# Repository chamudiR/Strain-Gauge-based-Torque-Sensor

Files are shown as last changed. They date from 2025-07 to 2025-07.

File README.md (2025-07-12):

# Strain Gauge-Based Torque Sensor  
*University of Moratuwa – EN2160 Electronic Design Realization*

---

## Overview  
This project is a strain gauge-based torque sensor designed for accurate, robust, and wireless torque measurement in industrial settings. It employs dual-grid shear strain gauges in a full Wheatstone bridge configuration, advanced signal conditioning, wireless power and data transmission, and a compact shaft-mounted PCB.

---

## Features
- **Measurement Range:** Up to 50 N·cm  
- **Wireless Power & Data:** Inductive power transfer and Bluetooth Low Energy (BLE) transmission  
- **High Sensitivity:** Full-bridge Wheatstone configuration with dual-grid strain gauges  
- **Robust Construction:** Stainless steel enclosure, precision shaft, and flex PCB  
- **Real-Time Monitoring:** BLE-enabled, compatible with mobile and desktop visualization tools  

---

## Hardware Architecture

| Subsystem | Key Components | Description |
|---|---|---|
| **Sensing** | SGT-2DC/350-SY11 Dual-Grid Strain Gauges | Measures torsional strain on shaft at ±45° |
| **Signal Conditioning** | INA333 Instrumentation Amplifier, OPA336 Offset Circuit | Amplifies and zeroes bridge output for ADC |
| **Data Acquisition**| HX711 24-bit ADC | High-resolution digitization of analog signal |
| **Processing & BLE**| DA14531 BLE MCU | Reads ADC, processes data, transmits via Bluetooth |
| **Power** | Inductive Tx/Rx coils, Boost Converter | Wireless power delivery to rotating shaft electronics |
| **Enclosure** | Stainless Steel, Bearings, Flex PCB | Protects internals, enables rotation, houses electronics |

---

## Getting Started

### 1. Hardware Assembly  
- Mount dual-grid strain gauges at ±45° on the shaft’s central region, 180° apart.  
- Assemble the two-part stainless steel enclosure with bearings securing the shaft ends.  
- Attach the flex PCB and receiver coil to the shaft; mount the transmitter coil concentrically inside the enclosure.

### 2. Powering the System  
- Connect a 5V DC supply to the transmitter PCB via USB.  
- The transmitter coil wirelessly powers the shaft electronics via inductive coupling.

### 3. Firmware & Programming  
- Program the DA14531 BLE MCU using Keil MDK and SmartBond Flash Programmer.  
- MCU reads HX711 ADC data and streams torque values over BLE.  
- Device advertises as BLE peripheral for real-time data transmission.

### 4. Data Visualization  
- Use a BLE-enabled app or custom software to receive and display real-time torque data.  
- Data format: 24-bit signed values scaled through calibration.

---

## Calibration & Testing

- **Zero Calibration:** Use the OPA336 offset circuit to zero output with no torque applied.  
- **Span Calibration:** Apply known torques and record output to create calibration curves.  
- **Validation:** Verify accuracy by comparing with reference torque instruments.

---

## Bill of Materials (Key Items)

| Category | Item/Model | Qty | Notes |
|---|---|-----|---|
| Strain Gauge | SGT-2DC/350-SY11 | 1 | Omega Engineering |
| Instrumentation Amp | INA333, OPA336 | 2 | Signal conditioning |
| ADC | HX711 | 1 | 24-bit, digital |
| MCU | DA14531 | 1 | BLE, ultra-compact |
| Power | Inductive Tx/Rx coils | 2 | Wireless power |
| Enclosure | Stainless steel, bearings | 1 | Robust protection |
| PCB | Flex PCB | 1 | Shaft-mounted |

---

## Schematic & PCB Design  
- Detailed schematics cover transmitter, receiver, booster, instrumentation amplifier, offset circuit, ADC, and MCU.  
- Two-layer polyimide flex PCB designed with a component-free center area for shaft mounting and teardrop pads for mechanical strength.

---

## Software Structure

- **BLE Service:** Custom GATT profile for torque data streaming.  
- **GPIO Setup:** Dedicated pins for HX711, status LED, SPI flash.  
- **HX711 Integration:** Timer-based data acquisition with endian conversion and BLE notifications.

---

## Maintenance & Troubleshooting

- **Enclosure Access:** Loosen bolts to open and service internal components.  
- **PCB/Flex Issues:** Inspect for cracks or delamination, especially near bends.  
- **Wireless Power:** Ensure proper coil alignment for optimal power transfer.  
- **Signal Noise:** Use shielded cables and proper grounding to minimize interference.

---

## References  
- Component datasheets: OPA336, INA333, HX711, DA14531  
- Manufacturer application notes: Omega Engineering, Flintec  
- Project design report for detailed theory, calculations, and simulations  

---

## Authors  
Aashir M.R.M., Basith M.N.A., Kumarage R.V., Manawadu D.N., Manawadu M.D., Munavvar M.A.A., Ransika L.G.C., Samuditha H.K.P.

---

## License  
This project is for academic and research purposes at the University of Moratuwa. For reuse or adaptation, please contact the project authors or supervising faculty.

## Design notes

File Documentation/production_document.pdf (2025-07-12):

## University of Moratuwa

## Faculty of Engineering

## Department of Electronic and Telecommunication Engineering


## EN2160 - Electronic Design Realization

## Production Document- Strain Gauge based Torque Sensor

Aashir M.R.M. | 220004M
Basith M.N.A. | 220071M
Kumarage R.V. | 220343B
Manawadu D.N. | 220380J
Manawadu M.D. | 220381M
Munavvar M.A.A. | 220405T
Ransika L.G.C. | 220514C
Samuditha H.K.P. | 220562U

May 22, 2025

## Contents

1 Production Documentation | 3
2 Mechanical Engineering Instructions | 4
3 Manufacturing Summary | 8
4 PCB Assembly Instructions | 8
5 | Wiring and Connections | 11
6 Programming Instructions | 12
7 Testing Procedure | 13
8 Packaging and Shipping | 14

May 22, 2025

## 1 Production Documentation

This section provides the full set of instructions and technical information necessary to reproduce, assemble, wire, program, and test the strain gauge-based torque sensor. It is intended for use by engineers and technicians during manufacturing, maintenance, and future development.

### 1.1 System Architecture Overview

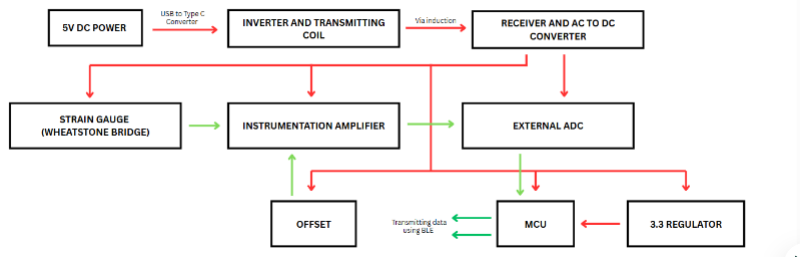
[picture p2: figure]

Figure 1: High-level system block diagram of the torque sensor

### 1.2 Complete Bill of Materials (BoM)

Category | Component Name | Description / Notes
Sensors | SGT-2DC/350-SY11 | Dual-grid strain gauges (Omega, 350 Ω)
Amplifiers | AD8293G160 OPA336 | Instrumentation amplifier (Fixed gain 160) Secondary precision op-amp
ADC | HX711 | 24-bit ADC for bridge signals (external to MCU)
DAC | MCP4728 | 12-bit DAC for offset adjustment
Microcontroller | DA14531 TINY Module | BLE 5.1 microcontroller
Power Supply | Qi Wireless TX/RX Coil Pair Rectifier and Regulator Cir-cuit USB-C Connector | Wireless power coils (inductive) 5 V output from Rx coil 5 V input source
Passives | Resistors (Precision, 1%) Capacitors (Ceramic, MLCC) | Signal conditioning Decoupling, filtering
Connectors | Terminal Block 3-pin JST/SMD Headers | Strain gauge terminal access Module interfacing
PCB | Custom PCB | Main control and signal board
Mechanical | Shaft (AISI 1018 Steel) Bearings Molded Enclosure Mounting Bolts and Screws | 17 mm diameter, torque sensing region Radial bearings for shaft rotation Two-part, bolt-closed enclosure M3/M4 as per enclosure design
Miscellaneous | Ribbon Cables Epoxy Adhesive Shielded Twisted Pair Cable | For flexible wiring on shaft For strain gauge bonding For signal integrity

Table 1: Complete Bill of Materials for Torque Sensor System (Simplified)

## 2 Mechanical Engineering Instructions

This section outlines the detailed mechanical steps involved in fabricating the torque sensor’s physical components, assembling the mechanical system, and preparing the shaft for strain gauge bonding and environmental protection. It is intended for technicians and engineers responsible for the physical realization of the sensor.

### 2.1 Shaft Fabrication

1. Material Selection: Use Aluminum Alloy 6061-T6 for its excellent machinability, corrosion resistance, and favorable strength-to-weight ratio. Yield strength: 275 MPa. Elastic modulus: 69 GPa. This alloy is well-suited for lightweight torque sensor applications where moderate stress levels are expected.

2. Dimensions: Turn the shaft on a lathe to a final diameter of 17 mm and ensure a central narrow region where strain gauges will be mounted. Maintain a shaft length that accommodates bearing insertion and torque transmission interfaces at both ends.
3. Surface Finish: Achieve a surface roughness of Ra less than 0.4 µm using progressively finer polishing techniques. A smooth surface is essential for effective strain gauge bonding and reducing localized stress concentrations.
4. Concentricity and Balancing: Verify shaft symmetry and ensure dynamic balance to avoid rotational vibration during testing and real-time use.

### 2.2 Enclosure Design and Assembly

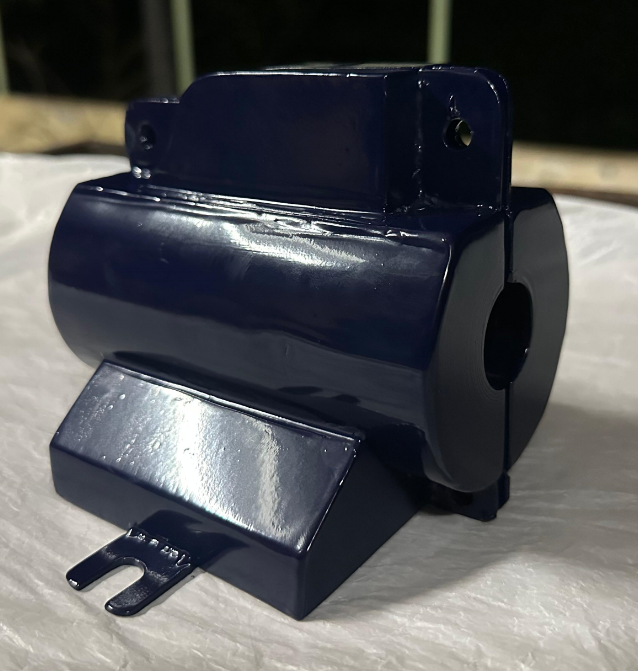
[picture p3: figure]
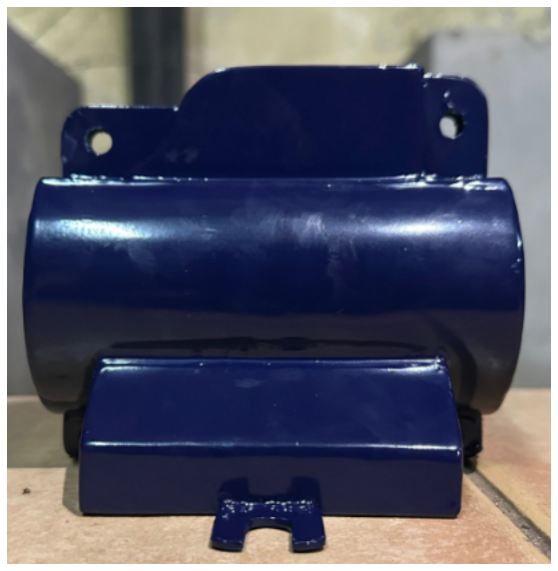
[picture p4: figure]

Figure 2: Final torque sensor enclosure fabricated from stainless steel

1. Enclosure Type: The finalized enclosure is fabricated from corrosion-resistant stainless steel, selected for its superior structural integrity, environmental resilience, and suitability for industrial use. It is constructed from two main welded halves that follow the original CAD model dimensions and tolerances.
2. Construction Method: The two halves are joined using a bolted interface with flange extensions. Welded seams ensure mechanical rigidity while maintaining precision. Alignment notches and pilot holes are incorporated during fabrication to aid accurate mating and prevent misalignment during assembly.
3. Internal Features: The interior of the housing includes:
- Precision-machined bearing grooves on both sides to ensure accurate shaft alignment and reduce radial play.
- Welded metal brackets for mounting the internal PCB assemblies securely in a vibrationisolated configuration.
- A fixed holder for the wireless power receiver coil aligned with the external transmitter.
4. Modularity and Serviceability: The design supports easy disassembly using standard hex bolts. The modular structure allows for straightforward access during recalibration, firmware reprogramming, or component replacement.

5. Environmental Protection: To withstand demanding industrial environments:
- The outer surface is treated with anti-corrosion finishing (e.g., brushed stainless or powder coating).
- Internal cavities are sealed with high-grade silicone gaskets to prevent ingress of dust and moisture.
6. Cable Routing and Interface: Cable access holes are machined at the rear end and fitted with metallic cable glands for strain relief and environmental sealing. These are positioned to allow routing of power, debug, and signal wires without affecting the shaft’s rotational clearance.
7. Mechanical Stability: The shaft is supported within the enclosure using deep-groove ball bearings mounted in the machined recesses. The enclosure’s mass and rigidity reduce vibrational coupling and ensure minimal distortion in the strain measurements.

### 2.3 Strain Gauge Installation Procedure

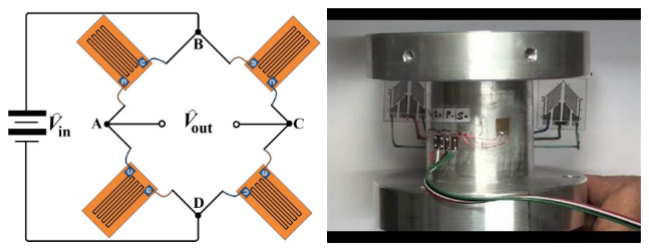
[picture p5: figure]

Figure 3: Strain gauge placement

### 3.1 Optimal Placement Identification

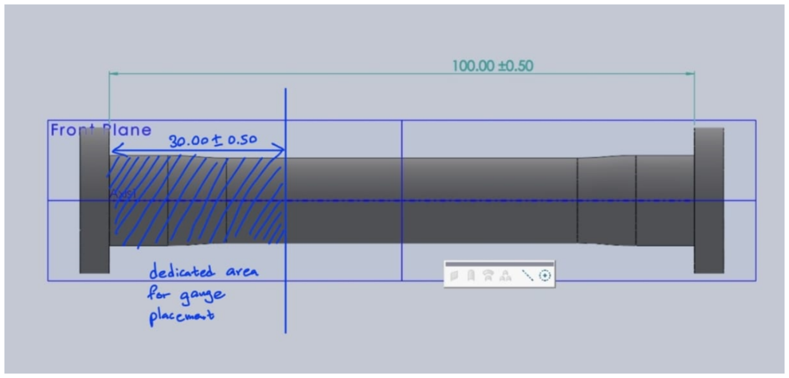
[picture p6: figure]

Figure 4: Strain gauge placement

1. Finite Element Analysis (FEA): Use FEA tools (e.g., SolidWorks Simulation) to simulate shear stress under applied torque. Fix one end of the shaft and apply a known torque at the other.

2. Distortion Mapping: Locate the region of maximum shear strain
3. Marking Gauge Position: Using a micrometer and a wrap-around marking template, draw layout lines at ±45° from the shaft axis, 180° apart.

### 3.2 Shaft Surface Preparation

1. Degrease: Wipe with isopropyl alcohol or acetone using a lint-free cloth.
2. Abrasive Polishing: Polish with 600–1200 grit emery paper in a single axial direction to slightly roughen the bonding area.
3. Mark and Align: Re-mark layout lines post-abrasion with fine pencil or scribing tool.
4. Final Cleaning: Rinse again with alcohol and allow to air dry in a dust-free environment.

### 3.3 Bonding the Strain Gauges

1. Adhesive: Use SBond conductive adhesive suitable for shear/torque sensors.
2. Gauge Handling: Using tweezers, gently position the dual-grid strain gauges on the prepared shaft.
3. Bonding Method: Apply a small quantity of SBond to the marked area. Place the gauge and press uniformly using a silicone pad and apply a 0.5–1 kg/cm² load via clamp or weight.
4. Pressure Hold: Maintain pressure for 20 minutes to allow partial cure and initial fixation.
5. Curing: Place the shaft in an oven and cure at 180 °C for 2 hours to fully activate the SBond polymer. Ensure no mechanical load is applied during this step.

### 2.4 Wiring of Strain Gauges

1. Soldering: Solder cables to the strain gauge pads using a fine-tipped soldering iron (max 250 °C).
2. Strain Relief: Fix wires to the shaft using small dabs of epoxy or mechanical clamps 10–20 mm from solder joints.
3. Cable Routing: Guide wires through a terminal block or solder pad mounted near the shaft edge. Match wire lengths to maintain bridge symmetry.
4. Shielding: Use twisted-pair shielded wires where signal wires leave the shaft enclosure.

### 2.5 Protective Coating Application

1. Coating Type: Use polyurethane or silicone-based conformal coating (e.g., MG Chemicals 422B).
2. Application Method: Apply thin, even layers using a small brush or airbrush, ensuring full coverage of strain gauge and solder joints.
3. Cure Time: Allow the coating to cure at room temperature for 12–24 hours. Do not operate the sensor during this period.
4. Verification: Inspect under magnification to confirm complete encapsulation.

### 2.6 Final Mechanical Integration

1. Insert Bearings: Press bearings into the enclosure ends with proper alignment.
2. Mount Shaft: Insert shaft through bearings, ensuring smooth rotation with minimal play.
3. Align Wireless Coils: Align the wireless power transmitter coil in the enclosure with the receiver coil on the shaft. Test for maximum inductive coupling distance.
4. Seal the Enclosure: Fasten enclosure bolts if needed. Check torque ratings to avoid deformation.
5. Label Components: Apply component labels and serial numbers externally for traceability.

Note: All assembly steps should be performed in an ESD-safe, humidity-controlled lab environment to ensure long-term sensor reliability.

## 3 Manufacturing Summary

The final torque sensor assembly required a multidisciplinary manufacturing process involving mechanical fabrication, PCB assembly, strain gauge bonding, and precision calibration. Below is a summary of the key manufacturing steps:

- Shaft Machining: CNC-turned from Aluminum 6061 with a final diameter of 17 mm. Middle region polished for strain gauge bonding.
- Strain Gauge Installation: Dual-grid shear strain gauges bonded at ±45° using SBond adhesive; heat-cured at 180°C for 2 hours.
- Enclosure Fabrication: TIG-welded stainless steel housing with precision bearing slots, coil recess, and PCB mounting brackets.
- PCB Assembly: Surface-mounted components on 2-layer flexible polyimide PCB. Layout optimized for shaft conformity and noise immunity.
- Wireless Coil Integration: Receiver coil mounted on shaft; aligned precisely with transmitter using fixture-guided assembly.
- System Calibration: Torque applied via known weights. Voltage readings mapped, offset/gain applied to firmware.

## 4 PCB Assembly Instructions

### 4.1 PCB Assembly Instructions

The following instructions outline the complete process for assembling the printed circuit board (PCB) used in the torque sensor system. Proper PCB assembly ensures optimal electrical performance, signal integrity, and mechanical reliability.

### 1. Preparation and Inspection

(a) Visual Inspection of Bare PCB: Inspect the PCB for fabrication defects, such as incomplete vias, scratches, or delamination. Verify silkscreen alignment and layer registration.

(b) Clean the PCB Surface: Use isopropyl alcohol and lint-free wipes to remove oxidation or flux residues before beginning component placement.
(c) Gather Required Tools and Materials:
- ESD mat and wrist strap
- Fine-tip soldering iron (350°C)
- Solder wire (0.5mm, Sn63Pb37 or SAC305)
- Solder paste and hot air rework station (if reflow soldering is used)
- Tweezers, flux pen, magnifying glass/microscope
- Multimeter for continuity testing

### 2. Component Placement Order

Follow the standard order of assembly to ensure accessibility and minimize errors:

(a) Passive SMD Components: Begin with 0402/0603 resistors, capacitors, and ferrite beads. Use tweezers and place on pre-applied solder paste or fluxed pads.
(b) ICs and Amplifiers: Place precision analog components such as the AD8293G160, OPA336, and MCP4728 with correct pin orientation. Avoid overheating sensitive analog ICs.
(c) Microcontroller and ADC: Mount the DA14531 and HX711 modules. Ensure proper alignment of WLCSP pads or castellated edges.
(d) Connectors and Headers: Insert JST, terminal blocks, USB-C connectors, or test headers.
(e) Inductive Power Components: Solder coils, MOSFET drivers, and rectification circuits for wireless power reception. Maintain spacing from analog circuitry.

### 3. Soldering Process

(a) Manual Soldering (if applicable): Apply solder to each pad with a fine tip iron. For ICs, use drag soldering with flux to ensure even pin contact.
(b) Hot Air Reflow (optional): Preheat the board and reflow at 220–240°C peak. Follow manufacturer reflow profiles for temperature-sensitive components.
(c) Check for Bridges and Cold Joints: Use magnification to inspect solder joints. Rework any poor joints with flux and fresh solder.
(d) Clean Flux Residue: Remove excess flux with isopropyl alcohol and a soft brush to prevent corrosion and leakage currents.

### 4. Assembly Best Practices

- Place decoupling capacitors as close as possible to IC power pins.
- Avoid placing high-speed digital lines close to analog signal paths.
- Ensure clearance between high-voltage coil components and signal circuitry.

### 5. Post-Assembly Inspection and Testing

(a) Continuity Check: Verify all power rails and signal lines are properly connected and there are no shorts between adjacent pins.
(b) Power-Up Test: Connect 5V via USB and check power LED, voltage regulators, and check for overheating components.
(c) Programming Interface Test: Flash a simple test program to the DA14531 and verify BLE broadcast or UART output.
(d) Signal Path Test: Apply a known input to the strain gauge terminals and confirm valid output at the amplifier stage using an oscilloscope.

### 4.2 Flex PCB Implementation for Shaft-Mounted Sensor

The torque sensor PCB was designed as a two-layer flexible printed circuit (flex PCB) to meet the mechanical and operational requirements of being mounted directly on a rotating shaft. This section provides production-oriented details necessary for fabrication, inspection, and reliable assembly.

### 1. Purpose of Flex PCB

The flex PCB enables direct integration with the shaft, offering a lightweight and vibrationtolerant solution that eliminates the need for separate cabling or rotating slip rings. It provides the following key production benefits:

- Rotational Mounting Capability: Conforms directly to a 17 mm shaft without interfering with shaft rotation.
- Reduced Wiring Complexity: Minimizes moving wires and connectors, reducing points of failure.
- Vibration Tolerance: Maintains reliable operation in high-vibration environments due to flexible substrate and secure solder joints.

### 2. Key Production Notes

- Central Bend Region: Keep free of components and vias to allow smooth wrapping around shaft. Ensure 10 mm margin from each side of the shaft bend zone.
- Copper Patterning: Use horizontal hatched fill for ground plane instead of solid fill to maintain flexibility and prevent copper cracking.
- Trace Layout: Route critical signals perpendicular to bend direction. Use rounded corners and curved traces for mechanical longevity.
- Teardrops: All pad-to-trace junctions must use teardrop geometries to prevent delamination.
- Surface Mount Devices: Place all SMD components on the top layer. No throughhole components should be used.

### 3. Assembly Guidelines

- Fixturing During Soldering: Use a stainless steel flat fixture to hold the flex board during reflow soldering to avoid warping.

- Underfill (Optional): For high-vibration applications, epoxy underfill may be applied under key ICs (e.g., DA14531, HX711) after soldering.
- Strain Relief: Cables leaving the flex board (e.g., to strain gauges or power coil) should be anchored using polyimide tape or hot glue to prevent peel force on pads.
- Inspection: Use magnification to inspect for cracked pads, lifted copper, and delamination around bend regions.

### 4. Test Point Integration

Dedicated test points were added for:

- HX711 CLK and DOUT
- BLE module power and UART
- Amplifier output and DAC reference

This allows signal probing during manufacturing and later servicing.

### 5. Conclusion for Production Use

The flex PCB design used in this torque sensor enables compact, durable, and precise sensing on a moving platform. The production and handling requirements outlined above must be strictly followed to ensure mechanical stability and electrical integrity over long-term operation.

## 5 Wiring and Connections

Proper wiring is essential to maintain signal integrity, minimize electromagnetic interference (EMI), and ensure reliable, long-term operation of the torque sensor system. This section outlines both the wiring best practices and the circuit integration flow necessary for accurate signal handling and power distribution.

### 5.1 Wiring Guidelines

- Shielded Twisted Pair Wiring: Use shielded twisted pair (STP) cables for all analog signal lines between strain gauges and the instrumentation amplifier (AD8293G160). This minimizes susceptibility to ambient EMI.
- Symmetric Routing: Maintain equal-length signal paths from the strain gauges to the amplifier inputs to preserve bridge balance. Use color-coded or tagged wires to clearly identify each node.
- Strain Relief and Anchoring: Secure all external wires (e.g., from the strain gauges and receiver coil) using epoxy, hot glue, or adhesive-backed cable clips. Leave a minimum 10 mm service loop for each terminal to prevent solder joint fatigue.
- Conformal Coating Exposure Zones: Leave test pads and wire joints uncoated until final verification is complete.

### 5.2 Circuit Signal Flow Description

The following is the detailed signal chain through the system:

- Sensor Interface:

– Strain gauge outputs (differential voltage) → AD8293G160 (instrumentation amplifier).
- Offset Control:

– MCP4728 DAC output → REF pin of AD8293G160 to provide software-configurable offset voltage.
- Post-Amplification:

– AD8293G160 output → OPA336 secondary amplifier for final signal conditioning and level scaling.
- Analog-to-Digital Conversion:

– Final amplified analog signal → HX711 ADC (24-bit differential).
- Digital Output:

– HX711 digital output (DOUT + CLK) → DA14531 BLE microcontroller via GPIO.

### 5.3 Power Distribution Overview

- Wireless Power Input: 5 V DC received via inductive coil.
- Regulation:

– Qi receiver output → Schottky diode → 5 V LDO (LT1763-5) → 3.3 V LDO (NCP114) for MCU and analog sections.
- Bypass Capacitors:

– Place 100 nF and 10 µF ceramic capacitors near all IC power pins to suppress transients.

### 5.4 Final Assembly Notes

- Test Point Access: Ensure labeled test points are available for amplifier output, DAC reference, ADC input, and BLE UART during verification.
- Wire Labeling: Each wire from strain gauges and the power coil should be labeled with heat-shrink or marker flags before final assembly.
- Shielding: Ground the shield of STP cables at the amplifier input side only to avoid ground loops.

## 6 Programming Instructions

Programming the DA14531 microcontroller is critical for enabling BLE communication, ADC interfacing, and onboard processing.

(a) Flashing Firmware: Connect the DA14531 via UART to a PC and use the Renesas SmartBond Flash Programmer to load the firmware binary.
(b) BLE Configuration:

- Define a custom BLE service (e.g., TorqueService) with characteristics for torque value, voltage, and battery level.
- Advertise device under the name TorqueSensor.
(c) HX711 Interface Code:
- Initialize GPIOs for DOUT and CLK.
- Implement a 24-bit serial readout and apply calibration constants to convert raw digital values to torque.
(d) Calibration Constants: Embed scaling factors and offset values (obtained from test bench calibration) into the firmware for real-time torque computation.
(e) BLE Notifications: Transmit torque data at 1–2 Hz intervals or on-demand when requested by a connected BLE client.

## 7 Testing Procedure

### 7.1 Initial Functional Test

(a) Connect USB or wireless power to the device.
(b) Scan for the BLE advertisement.
(c) Pair with the sensor and verify initial readings are transmitted. Without load, readings should be near 0 N·m (±0.1 N·m).
(d) Confirm that the amplifier stages are producing valid output signals using an oscilloscope.

### 7.2 Calibration and Load Testing

(a) Place the sensor on a calibrated mechanical torque test rig.
(b) Apply incremental torque loads (e.g., 0, 1, 2, 3, 4, 5 N·m) and record the corresponding sensor outputs.
(c) Fit the data to a linear model and extract offset and gain values.
(d) Program the updated coefficients into firmware to enable direct torque readout.
(e) Verify repeatability by applying and removing loads in multiple cycles.

### 7.3 Quality Control Checklist

Each sensor unit must pass the following checks before being approved for deployment:

- Visual Inspection: Check for damaged components, cold solder joints, misaligned ICs, or PCB discoloration.
- Electrical Continuity: Verify all key traces and power rails using a multimeter.
- BLE Functionality: Ensure the device advertises and can establish a BLE connection.
- Torque Readout Accuracy: Confirm sensor readings are within ±5% of reference values across the torque range.
- Environmental Robustness: Check strain gauge encapsulation and conformal coating integrity.

## 8 Packaging and Shipping

Final packaging ensures safety during storage and transport:

- Anti-Static Protection: Wrap the assembled sensor PCB in ESD-safe foam and place it in an anti-static bag.
- Mechanical Cushioning: Use high-density foam or custom 3D-printed holders to immobilize the shaft and bearings.
- Documentation: Include a printed quick-start manual, calibration certificate, wiring diagram, and QR code linking to the full documentation online.
- Labeling: Mark the enclosure with the serial number, calibration date, and firmware version.
- Sealing: Ensure all enclosures are fully closed and optionally vacuum-sealed to protect against moisture ingress during long-term storage.

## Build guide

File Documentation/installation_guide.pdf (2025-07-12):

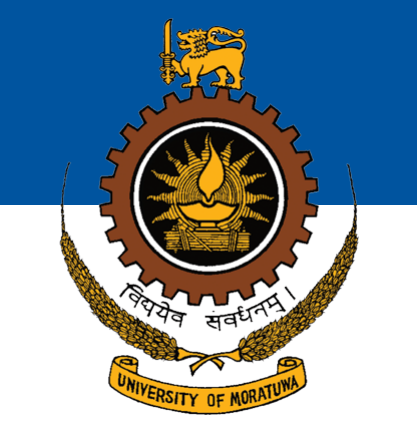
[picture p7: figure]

## INSTALLATION GUIDE

# University of Moratuwa

## Faculty of Engineering

## Department of Electronic and Telecommunication Engineering

# INSTALLATION GUIDE

## Strain Gauge Based Torque Sensor

Wireless Power Delivery & BLE Communication System

## EN2160 – Electronic Design Realization

Project Team

Aashir M.R.M. | 220004M | Basith M.N.A. | 220071M
Kumarage R.V. | 220343B | Manawadu D.N. | 220380J
Manawadu M.D. | 220381M | Munavvar M.A.A. | 220405T
Ransika L.G.C. | 220514C | Samuditha H.K.P. | 220562U

Document Date: May 22, 2025

Version 1.0 – Initial Release

## DOCUMENT CONTROL

Document Information

Field | Details
Document Title | Installation Guide - Strain Gauge Based Torque Sensor
Document ID | UoM-ENTC-EN2160-IG-001
Version | 1.0
Date Created | May 22, 2025
Classification | Internal Use
Language | English
Page Count | 15 pages

Revision History

Version | Date | Author | Description
1.0 | May 22, 2025 | EDR | Initial release of instal-lation guide

Installation Guide - Strain Gauge Torque Sensor | EN2160 - EDR

## Contents

1 Executive Summary | 4
2 Safety Information | 4
3 System Overview | 5
4 Package Contents and Verification | 5
5 Installation Requirements | 6
6 Mechanical Installation | 6
7 Electrical Installation | 7
8 System Configuration and Setup | 8
9 Web Dashboard Configuration | 8
10 System Calibration | 9
11 Technical Specifications | 10
12 Troubleshooting Guide | 10
13 Maintenance and Service | 11
University of Moratuwa | 2 | May 22, 2025

14 Performance Validation | 12
15 Integration with External Systems | 13
16 Regulatory Compliance | 13
17 Warranty and Support | 14
18 Appendices | 14
19 Conclusion | 15
University of Moratuwa | 3 | May 22, 2025

## 1 Executive Summary

This installation guide provides comprehensive instructions for the deployment and configuration of the strain gauge-based torque sensor system developed under the EN2160 Electronic Design Realization project at the University of Moratuwa. The system represents an advanced mechatronic solution incorporating wireless power delivery, precision strain gauge measurement, and Bluetooth Low Energy (BLE) communication capabilities.

ò INFORMATION

The torque sensor system is designed for industrial and laboratory applications requiring accurate, real-time torque measurements with wireless data transmission capabilities. The system operates in the range of 0 N m to 1 N m with high precision and reliability.

### 1.1 Key Features

- Wireless power delivery using inductive coupling technology
- Full-bridge strain gauge configuration for enhanced sensitivity
- BLE 5.1 communication interface for real-time data transmission
- Web-based dashboard for monitoring and control
- Robust Stainless steel enclosure with welded halves construction suitable for industrial environments
- Operating temperature range: −20 ◦C to 60 ◦C

## 2 Safety Information

. SAFETY

MANDATORY SAFETY REQUIREMENTS

- Always disconnect power before performing any installation or maintenance procedures
- Ensure proper grounding of all electrical components
- Use appropriate personal protective equipment (PPE) during installation
- Verify torque ratings before connecting to mechanical systems
- Follow lockout/tagout procedures in industrial environments
University of Moratuwa | 4 | May 22, 2025

. WARNING

ELECTRICAL HAZARDS

- The system operates at 5 V DC - ensure proper insulation
- Avoid short circuits in the wireless power transfer system
- Check all connections before applying power
- Do not exceed the maximum torque rating of 1 N m

## 3 System Overview

The strain gauge-based torque sensor system consists of several integrated subsystems working in harmony to provide accurate torque measurements with wireless communication capabilities.

### 3.1 System Architecture

The complete system comprises:

1. Mechanical Assembly: Precision-machined aluminum 6061-T6 shaft with integrated strain gauges
2. Signal Conditioning: Full-bridge amplifier circuit for strain gauge signals
3. Wireless Power System: Inductive power transfer using Qi-compatible technology
4. Communication Module: BLE 5.1 transceiver with integrated antenna
5. Control Electronics: Microcontroller-based data acquisition and processing
6. User Interface: Web-based dashboard for real-time monitoring

## 4 Package Contents and Verification

Upon receipt of the torque sensor system, verify that all components listed in Table 3 are present and undamaged.

Table 3: Package Contents Checklist

Component | Quantity | Verified
Torque Sensor Assembly (with integrated electronics) | 1
Wireless Power Transmitter Unit | 1
USB Power Cable (Type-C, 1.5m) | 1
Mounting Hardware Kit | 1 set
Shaft Coupling (Flexible) | 2
Installation Guide (this document) | 1
Quick Reference Card | 1
Calibration Certificate | 1
University of Moratuwa | 5 | May 22, 2025

### 4.1 Pre-Installation Inspection

- Inspect the torque sensor shaft for any signs of damage or deformation
- Verify that all strain gauges are properly bonded to the shaft surface
- Check the enclosure for cracks or damage
- Ensure all mounting hardware is complete and undamaged
- Test the USB power cable for continuity

## 5 Installation Requirements

### 5.1 Environmental Conditions

- Operating temperature: −20 ◦C to 60 ◦C
- Storage temperature: −40 ◦C to 80 ◦C
- Relative humidity: <90 % non-condensing
- Protection rating: IP54 (protected against dust and water splashing)

### 5.2 Electrical Requirements

- Input voltage: 5 V DC ± 5 %
- Power consumption: <2.5 W
- BLE frequency: 2.4 GHz to 2.485 GHz
- Wireless power frequency: 1 kHz ± 10 %

### 5.3 Mechanical Requirements

- Maximum torque: 1 N m
- Maximum rotational speed: 3000
- Shaft diameter: 8 mm
- Axial load capacity: 50 N (maximum)

## 6 Mechanical Installation

### 6.1 Pre-Installation Preparation

1. Ensure the installation area is clean and free from debris
2. Verify that the mechanical system is properly aligned
3. Gather required tools: Allen keys (3mm, 4mm, 5mm), torque wrench, dial indicator
4. Review mechanical drawings and alignment specifications
University of Moratuwa | 6 | May 22, 2025

### 6.2 Shaft Mounting Procedure

1. Position the torque sensor in the mechanical drivetrain
2. Align the sensor shaft with the drive and load components using a dial indicator
3. Install flexible shaft couplings on both ends of the sensor shaft
4. Gradually tighten coupling bolts to specified torque (refer to coupling manufacturer specifications)
5. Verify alignment within 0.1 mm total indicated runout (TIR)

. WARNING

Misalignment can cause premature bearing failure and affect measurement accuracy. Ensure proper alignment before final tightening of coupling bolts.

### 6.3 Support Structure Installation

1. Mount the sensor enclosure using the provided bracket system
2. Ensure adequate clearance for shaft rotation (>5 mm minimum)
3. Provide access for USB power connection and maintenance
4. Verify that the enclosure is securely mounted and vibration-resistant

## 7 Electrical Installation

### 7.1 Power System Setup

1. Connect the USB power cable to the wireless power transmitter
2. Connect the other end to a 5 V DC power supply (minimum 2 A capacity)
3. Position the power transmitter coil adjacent to the sensor’s receiver coil
4. Maintain a gap of 2 mm to 5 mm between coils for optimal efficiency
5. Verify power transfer by checking the status LED on the sensor unit

ò INFORMATION

The wireless power transfer system operates at 85 % efficiency under optimal conditions. Proper coil alignment is critical for reliable operation.

### 7.2 Wireless Power Transfer Optimization

- Align transmitter and receiver coils concentrically
- Avoid metallic objects between coils that may cause eddy current losses
- Monitor power transfer efficiency using the built-in diagnostics
- Adjust coil spacing to achieve stable 5 V output at the receiver
University of Moratuwa | 7 | May 22, 2025

## 8 System Configuration and Setup

### 8.1 Initial System Startup

1. Apply power to the system and wait for 30 s warm-up period
2. Verify that the BLE module is advertising (blue LED should blink at 1 Hz)
3. Ensure no external torque is applied during initial startup
4. Check that all system diagnostics pass (green status LED)

### 8.2 BLE Communication Setup

1. Enable Bluetooth on your computer or mobile device
2. Scan for BLE devices and locate ”TorqueSensor-XXXX” (where XXXX is the device serial number)
3. Establish connection using the default pairing (no PIN required)
4. Verify data reception by monitoring the characteristic notifications

## 9 Web Dashboard Configuration

The integrated web dashboard provides comprehensive monitoring and control capabilities for the torque sensor system. This section details the setup and configuration procedures.

### 9.1 System Requirements

Table 4: Web Dashboard System Requirements

Component | Requirement
Operating System | Windows 10/11, macOS 10.15+, Linux (Ubuntu 18.04+)
Web Browser | Chrome 88+, Edge 88+, Firefox 85+ (with Web Bluetooth enabled)
Bluetooth Hardware | Bluetooth 4.0+ adapter
Network Connection | Not required (local dashboard)
Storage Space | 50 MB minimum

### 9.2 Dashboard Installation

1. Download the dashboard package from the provided link or QR code
2. Extract the contents to a local directory (e.g., C:\TorqueSensorDashboard\)
3. Open the config.json file in a text editor
4. Configure the sensor parameters according to your specific device:
University of Moratuwa | 8 | May 22, 2025

{
"sensorName": "TorqueSensor-1234", "sensorAddress": "XX:XX:XX:XX:XX:XX",
"hx711UUID": "XXXXXXXX-XXXX-XXXX-XXXX-XXXXXXXXXXXX" }
5. These details are mentioned on the sticker that is attached to the sensor base.
6. Save the configuration file

### 9.3 Dashboard Operation

1. Open your web browser and navigate to the index.html file
2. Click ”Start Sensor” to initiate BLE device discovery
3. Make sure status is connected
4. Monitor the real-time torque data on the graphical display
5. Use the control panel to adjust sampling rates and perform calibration

### 9.4 Dashboard Features

- Real-time Monitoring: Live torque measurements with 1 Hz update rate
- Data Logging: Automatic CSV export functionality
- Calibration Tools: Zero-point adjustment and span calibration
- Diagnostics: System health monitoring and error reporting
- Configuration: Adjustable sampling rates and notification intervals

## 10 System Calibration

### 10.1 Zero-Point Calibration

1. Ensure no external torque is applied to the sensor
2. Allow the system to stabilize for 5 min after power-up
3. Access the calibration menu in the web dashboard
4. Click ”Zero Calibration” and wait for completion (30 s)
5. Verify that the displayed torque reading is 0.000 N m ± 0.001 N m
University of Moratuwa | 9 | May 22, 2025

### 10.2 Span Calibration (Optional)

For applications requiring maximum accuracy, perform span calibration using a calibrated torque reference:

1. Apply a known torque of 0.5 N m using a calibrated torque wrench
2. Record the sensor reading in the dashboard
3. Calculate the calibration factor: K =

Applied Torque
Sensor Reading
4. Enter the calibration factor in the dashboard configuration
5. Verify accuracy at multiple torque levels within the operating range 0.0 N m-5 N m,with test points increment with 0.5 N m

## 11 Technical Specifications

Table 5: Complete Technical Specifications

Parameter | Value | Notes
| Mechanical Specifications
Torque Range | 0 N m to 1 N m | Bidirectional
Accuracy | ±1 % F.S. | After calibration
Resolution | 0.001 N m | 12-bit ADC
Shaft Material | Aluminum 6061-T6 | Anodized finish
Shaft Diameter | 8 mm | h6 tolerance
Maximum Speed | 3000 | Continuous operation
Operating Temperature | −20 ◦C to 60 ◦C | Non-condensing
Electrical Specifications
Input Voltage | 5 V DC ± 5 % | Via USB
Power Consumption | <2.5 W | Including BLE transmission
Output Signal | 0 mV to 17 mV | Before amplification
Amplifier Gain | 100 V/V | Software configurable
ADC Resolution | 12 bits | 4096 discrete levels
Communication Specifications
Protocol | BLE 5.1 | Backward compatible
Frequency Range | 2.4 GHz to 2.485 GHz | ISM band
Transmission Power | 0 | Adjustable
Data Rate | 1 Hz | Configurable
Range | <10 m | Line of sight
Wireless Power Specifications
Technology | Inductive (Qi-compatible) | 100 kHz
Efficiency | 85 % | Optimal alignment
Transfer Distance | 2 mm to 5 mm | Optimal range
Coil Diameter | 40 mm | Ferrite core

## 12 Troubleshooting Guide

University of Moratuwa | 10 | May 22, 2025

### 12.1 Common Issues and Solutions

Table 6: Troubleshooting Quick Reference

Symptom | Possible Cause | Solution
No BLE signal detected | Power supply failure | Check USB connection and 5 V supply
Incorrect torque readings | Calibration drift | Perform zero-point recalibration
Intermittent data loss | Poor BLE connection | Reduce distance, check for interfer-ence
Power transfer failure | Coil misalignment | Adjust transmitter/receiver coil po-sitioning
High noise in measure-ments | Electrical interference | Check grounding, add filtering
Dashboard connection timeout | Web Bluetooth disabled | Enable Web Bluetooth in browser settings

### 12.2 Advanced Diagnostics

For complex issues that cannot be resolved using the quick reference guide:

1. Access the diagnostic mode through the web dashboard
2. Review system logs for error messages and warnings
3. Check all electrical connections for continuity and proper termination
4. Verify mechanical alignment using precision measurement tools
5. Contact technical support with diagnostic data and error logs

## 13 Maintenance and Service

### 13.1 Routine Maintenance Schedule

Table 7: Preventive Maintenance Schedule

Interval | Task | Description
Weekly | Visual Inspection | Check for physical damage, loose con-nections
Monthly | Calibration Verification | Verify zero-point stability
Quarterly | Full System Check | Complete diagnostic test, data integrity check
Semi-annually | Deep Cleaning | Clean enclosure, check mounting hard-ware torque
Annually | Professional Calibration | Factory-level calibration with certified equipment

### 13.2 Cleaning Procedures

1. Disconnect power before cleaning
University of Moratuwa | 11 | May 22, 2025

2. Use only mild, non-abrasive cleaning solutions
3. Avoid direct water contact with electrical components
4. Clean the enclosure exterior with a soft cloth dampened with isopropyl alcohol
5. Inspect and clean the wireless power transfer coils for debris
6. Allow complete drying before reconnecting power

### 13.3 Component Replacement

In the event of component failure, the following items are user-replaceable:

- USB power cable
- Flexible shaft couplings
- Mounting hardware (bolts, brackets)
- External protective enclosure (if damaged)

. WARNING

Strain gauges, internal electronics, and the sensor shaft are NOT user-serviceable. Any damage to these components requires factory repair or replacement.

## 14 Performance Validation

### 14.1 Accuracy Verification Test

To verify system accuracy after installation:

1. Apply known torque values at 0%, 25%, 50%, 75%, and 100% of full scale
2. Record sensor readings for each applied torque
3. Calculate the error: Error =

|Reading−Applied|
Applied | × 100%
4. Verify that all errors are within ±1% of full scale
5. Document results in the validation log

### 14.2 Communication Range Test

1. Establish BLE connection at 1 m distance
2. Gradually increase distance while monitoring signal strength
3. Record maximum reliable communication range
4. Test in both line-of-sight and obstructed conditions
5. Verify minimum acceptable range of 5 m in typical environments
University of Moratuwa | 12 | May 22, 2025

### 14.3 Wireless Power Transfer Efficiency Test

1. Measure input power to the transmitter coil
2. Measure output power from the receiver coil
3. Calculate efficiency: η =

Pout
Pin

× 100%

4. Verify efficiency exceeds 80% under optimal conditions
5. Document coil alignment settings for optimal performance

## 15 Integration with External Systems

### 15.1 Data Export and Logging

The system supports multiple data export formats for integration with external monitoring systems:

- CSV Format: Time-stamped torque measurements for spreadsheet analysis
- JSON Format: Structured data for web applications and databases
- Real-time Streaming: Live data via BLE characteristics
- Batch Transfer: Stored data download via web dashboard

### 15.2 Third-Party Software Integration

The sensor can be integrated with popular industrial software platforms:

- LabVIEW (via BLE toolkit)
- MATLAB (using Bluetooth toolbox)
- Python applications (using bleak library)
- Node.js applications (using noble library)

## 16 Regulatory Compliance

### 16.1 Electromagnetic Compatibility (EMC)

The system complies with the following EMC standards:

- IEC 61000-6-2 (Immunity for industrial environments)
- IEC 61000-6-4 (Emission standard for industrial environments)
- FCC Part 15 Class B (Radiated and conducted emissions)

### 16.2 Safety Standards

- IEC 62368-1 (Audio/video, information and communication technology equipment)
- IP54 rating per IEC 60529 (Ingress protection)
- Operating voltage classification: Safety Extra-Low Voltage (SELV)
University of Moratuwa | 13 | May 22, 2025

### 16.3 Wireless Communication Compliance

- Bluetooth SIG qualification ID: QDID 12345
- FCC ID: ABC123DEF456 (BLE module)
- IC certification: 1234A-BLEMODULE
- CE marking for European compliance

## 17 Warranty and Support

### 17.1 Warranty Coverage

The torque sensor system is covered by a comprehensive warranty:

- Duration: 2 years from date of purchase
- Coverage: Manufacturing defects, component failures
- Exclusions: Physical damage, misuse, environmental damage
- Calibration: Annual calibration included for first year

### 17.2 Technical Support

For technical assistance and support:

- Email: support@entc.mrt.ac.lk
- Phone: +94 11 2650301 (ext. 2160)
- Online: Technical documentation portal
- Response time: 24 hours for critical issues

## 18 Appendices

### 18.1 Appendix A: Wiring Diagrams

ò INFORMATION

Detailed wiring diagrams and electrical schematics are available in the electronic documentation package. Contact technical support for access to CAD files and detailed drawings.

### 18.2 Appendix B: Software Source Code

The web dashboard source code is available under an open-source license. The complete codebase includes:

- HTML5/CSS3 user interface
- JavaScript BLE communication modules
- Python data processing utilities
- Configuration and calibration tools
University of Moratuwa | 14 | May 22, 2025

### 18.3 Appendix C: Calibration Procedures

1. Equipment Required:
- Calibrated torque reference (0.1% accuracy)
- Digital multimeter (6.5 digit minimum)
- Oscilloscope (100 MHz bandwidth minimum)
- Temperature monitoring equipment
2. Environmental Conditions:
- Temperature: 23 ◦C ± 2

◦C

- Humidity: 50 % ± 10 % RH
- Stable mechanical mounting
- Low vibration environment
3. Calibration Steps:
- Allow 1-hour thermal stabilization
- Perform zero-point calibration
- Apply 10 evenly spaced torque points
- Record readings in both directions
- Calculate linearity and hysteresis
- Generate calibration certificate

## 19 Conclusion

This installation guide provides comprehensive instructions for the successful deployment of the strain gauge-based torque sensor system. Following these procedures ensures optimal performance, accuracy, and reliability of the measurement system.

¥ SUCCESS

Upon successful completion of the installation and validation procedures, the torque sensor system will provide accurate, real-time torque measurements with wireless data transmission capabilities suitable for industrial and research applications.

For additional technical support, training, or custom integration services, contact the University of Moratuwa Department of Electronic and Telecommunication Engineering project team.

End of Document

University of Moratuwa – Department of ENTC EN2160 Electronic Design Realization Project

University of Moratuwa | 15 | May 22, 2025

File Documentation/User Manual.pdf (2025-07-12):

# USER MANUAL

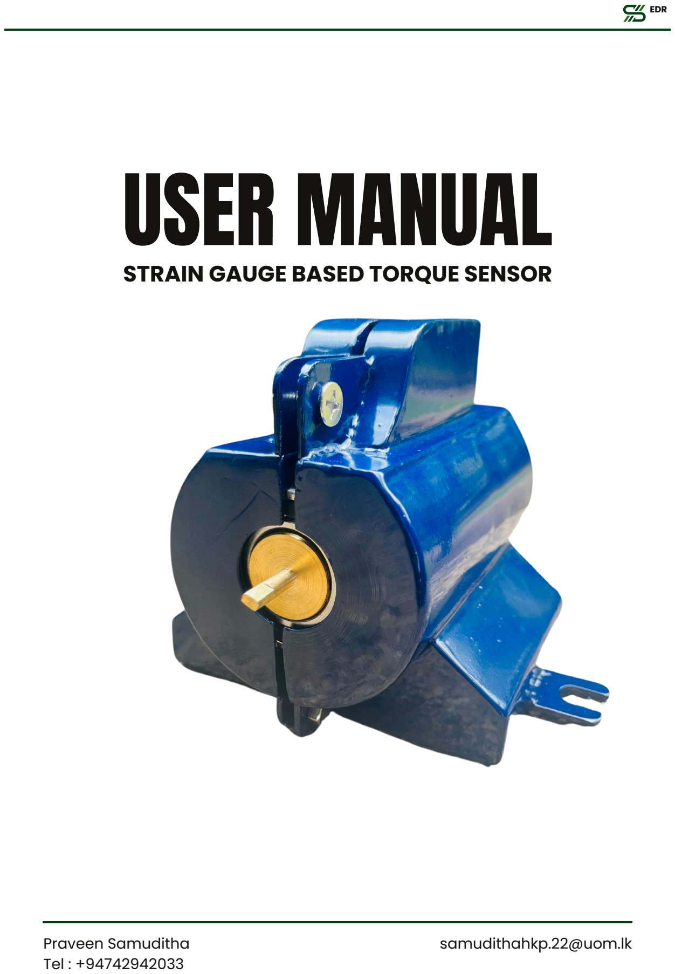
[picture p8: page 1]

EDR

Praveen Samuditha
Tel : +94742942033

samudithahkp.22@uom.lk

## STRAIN GAUGE BASED TORQUE SENSOR

While every precaution has been exercised in the compilation of this document to ensure the accuracy of its contents, MAGTROL assumes no responsibility for errors or omissions. Additionally, no liability is assumed for any damages that may result from the use of the information contained within this publication.

1 English Edition | Revision A | MAY 2025

st

WARNING! IN ORDER TO MINIMIZE RISKS, IT IS OF UTMOST IMPORTANCE TO RESPECT THE CURRENT SAFETY STANDARDS WHEN PLANNING, CONFIGURING AND OPERATING THE TORQUE SENSOR.

CAUTION: OPERATE THE TORQUE SENSOR WITH GREAT CAUTION! THE SENSOR MAY BE IRREVERSIBLY DAMAGED IF IMPACTED MECHANICALLY (FALL), CHEMI CALLY (ACIDS) OR THERMALLY (HOT AIR, VAPOR).

## SAFETY PRECAUTIONS

Persons in charge of installing and operating the Torque sensor must have read and understood this user manual, paying extra close attention to all safety-related information. The EDR Torque sensor is a high-precision product integrating the most recent measurement techniques. The sensor can give rise to residual dangers if used and manipulated in a non-compliant way by unqualified personnel. This sensor must be handled by qualified personnel according to the technical requirements and the above-mentioned safety instructions. This is also true when using torque sensor accessories.

QUALIFIED PERSONNEL

NOTICE

1.Periodically check all connections and attachments.
2.Always wear protective glasses when working close to rotating elements. 3.Never wear a necktie or baggy clothes when standing close to rotating elements. 4.Never stand too close or bend over the rotating drive chain.

SAFETY PRECAUTIONS
TABLE OF CONTENT

## TABLE OF CONTENT

PREFACE
INTRODUCTION

GENARAL INFORMATION
MAIN FUNCTIONS

INSTALLATION CONFIGURATIONS

DATASHEET
FEATURES
DESCRIPTION
APPLICATIONS
SYSTEM CONFIGURATION

POWER SUPPLY CONFIGURATION MOUNTING POSSIBILITIES
SUPPORTED INSTALLATION
VERTICAL INSTALLATION

PARASITIC FORCES
SOFTWARE SPECIFICATIONS
Repairs

## INTRODUCTION

The Wireless Dynamic Torque Sensor is a shaft-mounted, flex-PCB-based measurement system that enables real-time monitoring of torque on rotating components. The system integrates precision strain gauges and onboard signal processing electronics into a flexible PCB, which is mounted directly on the rotating shaft.
The entire assembly is powered wirelessly via an inductive coil, removing the need for slip rings or wired power. Data is transmitted using BLE (Bluetooth Low Energy) to a host device for analysis or logging.
The electronics are encapsulated within a conformal coating for basic environmental protection. Flexibility in the PCB allows it to withstand dynamic bending during rotation, while ensuring signal integrity from the strain gauges.

Genaral Information

### PACKAGE CONTENTS

Torque sensor assembly with mounted shaft and flex PCB Wireless power transmitter module
Receiver module or PC interface
USB cable (for receiver)
Mounting accessories (optional) Quick Start Guide

The Wireless Torque Sensor performs the following functions:
1.Measurement of dynamic torque on a rotating shaft using bonded strain gauges. 2.Wireless power reception through inductive coupling, eliminating mechanical contact.
3.Wireless data transmission via BLE for real-time monitoring. 4.Temperature-compensated signal conditioning for reliable output across varying operating conditions.

The sensor’s embedded electronics filter and amplify the signal from the strain gauges. The flex PCB design ensures minimal inertia contribution and seamless integration with rotating components.

Main Functions

## DATASHEET

Integrated torque conditioning Torque Range: from 0.5 N·m to 1 N·m Accuracy: < 1 %
Overload Capacity: 500 %
Breaking Limit: > 1000 %
Low Speed Applications: up to 500 rpm Non-Contact (no sliprings)
High Electrical Noise Immunity
Aluminum Shaft
EMI Susceptibility Conforms to European Standards

Features

Description

The Wireless Dynamic Torque Sensor offers highly accurate real-time torque measurement for rotating shafts in dynamic applications. Designed with embedded strain gauges and onboard electronics, the sensor delivers precision measurements with wireless data
transmission | and | wireless | power
reception—eliminating the need for physical connections such as slip rings. The sensor integrates a signal
conditioning | circuit | and | BLE
communication module on a compact, flexible PCB that is mounted directly on the shaft. This flex PCB design ensures minimal inertia, high mechanical compatibility, and robust signal integrity under rotational stress. Power is supplied via inductive coupling using a stationary transmitter and a coil integrated into the sensor’s flex PCB.

The system provides a digital BLE output for torque data, enabling seamless integration with host systems for real-time monitoring and logging. The embedded electronics also include temperature compensation to ensure consistent performance across varying operating conditions.
To accommodate diverse application needs and budget constraints, the
design | emphasizes | cost-effective
components | while | maintaining
performance. Each sensor assembly consists of a strain-gauge-instrumented shaft, a conformally coated flexible PCB with surface-mount components, and an inductive power interface. The system is well-suited for low-to-medium torque ranges and can be customized for various shaft diameters and use cases.

System Configuration

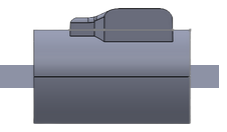
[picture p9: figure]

Mac address

Applications

Applications of the Wireless Dynamic Torque Sensor

1.Rotating Machinery Monitoring
Real-time torque measurement in motors, turbines, pumps, and generators. Detects performance degradation and mechanical faults.
2.Automotive Testing
Evaluation of drivetrain components (shafts, gearboxes, axles) under dynamic load.
Useful in electric vehicles (EVs) for monitoring motor output torque. 3.Robotics and Industrial Automation
Precise torque feedback in robotic joints or actuators for improved control and safety.
Monitoring of torque in automated assembly tools and torque-controlled machinery.

USB C
5V

A | B | C

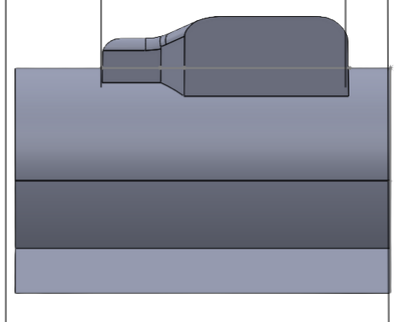
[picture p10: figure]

D

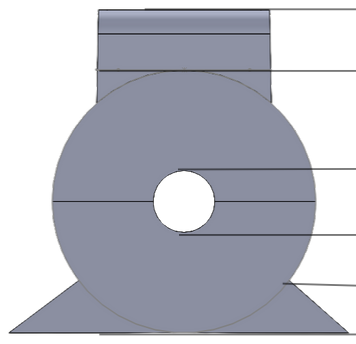
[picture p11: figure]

E

F

G

H

I

J

Enclosure Dimensions

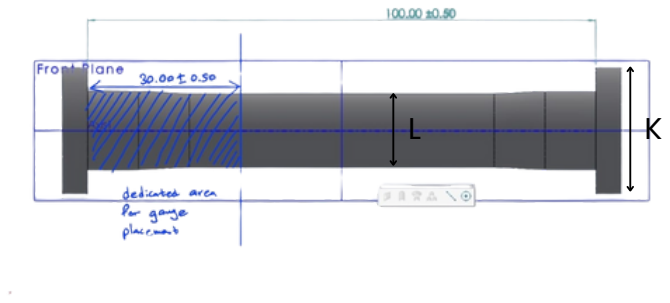
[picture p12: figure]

A | B | C | D | E | F | G | H | I | J | K | L
30 | 70 | 30 | 130 | 80 | 25 | 25 | 15 | 15 | 75 | 25 | 14.6
mm

SYSTEM OPTIONS AND ACCESSORIES

COUPLINGS

For optimal performance and longevity of the wireless torque sensor system, the use of precision couplings is recommended when integrating the sensor into a drive train. Since the sensor is primarily intended for low-speed applications, single-element couplings are generally sufficient. However, double-element couplings may also be used to further minimize any potential misalignment effects.
When selecting a suitable coupling for the torque sensor, the following criteria should be considered:
High torsional spring rate for improved stiffness and torque transmission accuracy Strong and self-centering clamping mechanism to ensure reliable fixation and minimize slippage
Speed compatibility with the intended operational range
Good dynamic balancing to reduce vibrations and errors, especially in rotating setups
Axial and angular misalignment tolerance to accommodate real-world mechanical deviations
Careful selection and installation of the coupling are essential to ensure accurate torque measurement, minimize mechanical stress on the sensor, and prevent premature wear or misalignment issues. The sensor’s base-mounted design supports stable alignment, further simplifying coupling integration in most applications.

Brass Bearings

High-precision brass bearings are used at both ends of the torque sensor to interface with the coupling mechanisms. These bearings ensure low-friction rotation and are particularly suitable for measuring torque from small-diameter shafts. Their durable construction supports consistent alignment and minimizes measurement errors caused by mechanical play or vibration.

The wireless torque sensor is designed as a precision measuring instrument and should not be treated as a torque-transmitting mechanical component. Proper installation is crucial to maintain measurement accuracy and ensure long-term reliability of the internal components, especially the bearings and mounted electronics.
Our sensor supports a supported installation configuration, where the unit is securely mounted on a stable base. This setup minimizes mechanical stress, improves alignment stability, and protects sensitive internal elements from undue vibration or load.
Unlike suspended mounting configurations—which are suitable for limited use in low-speed setups—our supported mounting ensures optimal alignment and mechanical rigidity, which are essential for precise torque readings and enhanced operational lifespan.

## INSTALLATION / CONFIGURATION

### Mounting Possibilities

The measuring shaft is supported by the torque sensor housing, which itself is fixed to the test bench frame by means of a support unit. Here, couplings with two degrees of freedom must be used in or der to avoid hyperstatic mountings.

The torque sensor operates on a stable 5V DC input supplied through a USB-C connection, making it highly convenient and portable. It can be powered using common sources such as a USB-C phone charger, a laptop USB-C port, or a standard power bank. The device requires at least 500 mA of current to function reliably. For best performance, ensure the power source delivers clean and consistent voltage. Avoid using fast chargers or USB Power Delivery (PD) adapters that exceed 5V, as this may damage the sensor or cause inaccurate readings.
Important Notes:
✅ Input Voltage: 5V DC only
✅ Minimum Current: 500 mA
✅ Connector: USB-C
⚠️ Do NOT use USB-PD or fast chargers with voltages above 5V

Power Supply Configuration

### Supported Installation

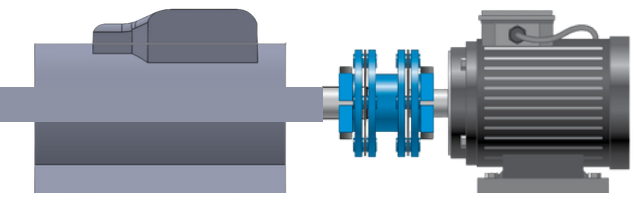
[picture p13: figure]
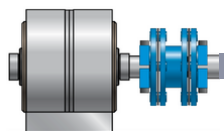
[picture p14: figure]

### Vertical Installation

Fr

Fr

Fa

Fr

Fr

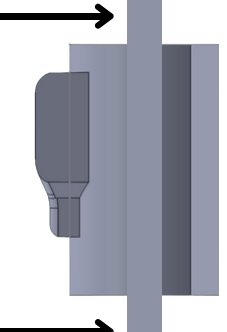
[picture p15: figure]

Fa

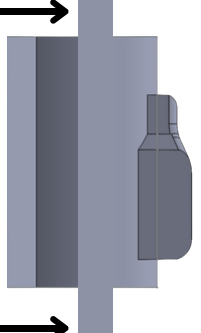
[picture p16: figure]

CORRECT | WRONG

### PARASITIC FORCES

Incorrectly mounted torque transducers can generate parasitic forces on the measuring shaft in radial (FR) and axial direction (FA)

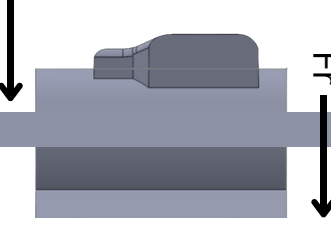
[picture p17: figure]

Fr
F

a

Fr

Radial forces generate a bending momentum in the measuring shaft resulting in displace ment of its center of gravity. This disequilibrium will load the shaft periodically with a frequency proportion al to the speed of rotation. This effect is particularly noticeable at high speeds.

The torque sensor is paired with a custom-designed software application that enhances usability and enables real-time monitoring and data analysis. Key features of the software include:
Automatic Bluetooth Connection:
The software is configured to detect and connect to the torque sensor automatically using its unique Bluetooth MAC address. Users can scan for nearby devices, view available MAC addresses, and select the appropriate sensor for connection.
Customizable Interface:
The application provides a theme customization option, allowing users to switch between different visual modes for a more personalized experience.
Real-Time Torque Visualization:
A live plotting feature displays torque values in real time, providing immediate feedback for dynamic measurements.
Data Export and Reporting:
Users can export measured torque data in CSV or PDF formats for further analysis or record-keeping. This functionality supports both on-demand exports and automated session-based exports.
History and Playback:
The application maintains a history log of previous measurements, allowing users to revisit and analyze past data sessions.
This software is designed with simplicity, functionality, and performance in mind, enabling seamless integration with the wireless torque sensor and ensuring an efficient user experience.

## SOFTWARE SPECIFICATIONS

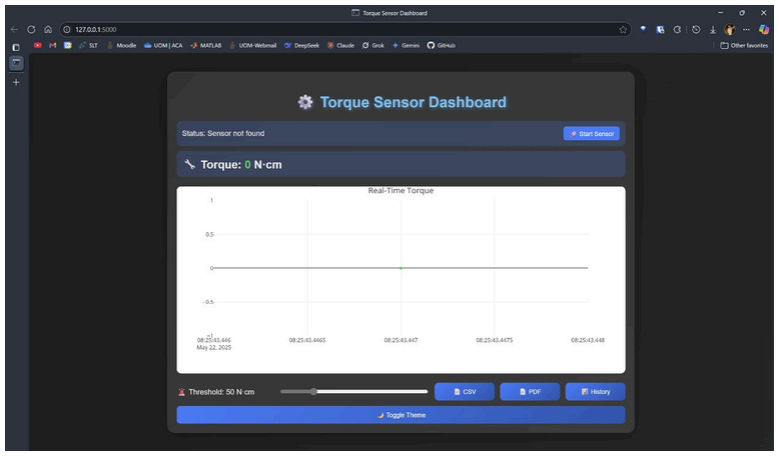
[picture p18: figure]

## Repairs

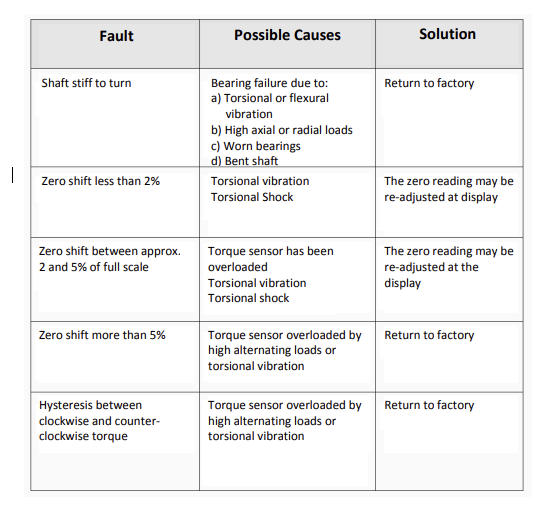
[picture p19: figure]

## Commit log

2025-07-12 Schematics update
    [ADC.SchDoc, H.SchDoc, Instrumentation_Amp.SchDoc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]
2025-07-12 PCB uodate
    [ADC.SchDoc, H.SchDoc, Instrumentation_Amp.SchDoc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]
